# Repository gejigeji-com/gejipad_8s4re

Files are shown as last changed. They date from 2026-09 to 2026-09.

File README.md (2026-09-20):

# gejipad_8s4re

自作キーボード「gejipad_8s4re」のハードウェア設計データ(KiCad)を公開するリポジトリです。

> **Note:** このリポジトリにはハードウェア(回路図・基板データ)のみを収録しています。ファームウェアはQMK Firmwareへの統合を申請中(`gejigeji/gejipad_8s4re`)であり、本リポジトリには含まれません。

## 概要

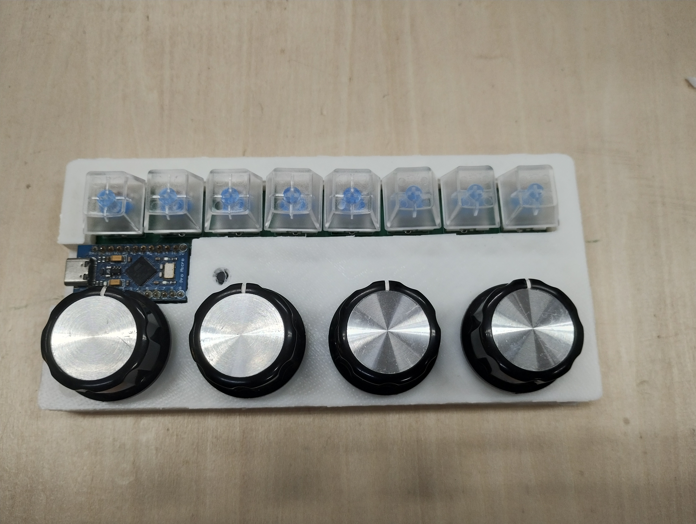
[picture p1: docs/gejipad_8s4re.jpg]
gejipad_8s4re


| 項目 | 内容 |
|---|---|
| キー数 | 8キー |
| ロータリーエンコーダ | 4基 |
| レイアウト | キー1列 + ロータリーエンコーダ1列 |
| MCU | ATmega32U4 |
| スイッチ | MX互換 |
| ファームウェア | [QMK Firmware](https://github.com/qmk/qmk_firmware) `gejigeji/gejipad_8s4re` として申請中(本リポジトリには含まれません) |

## リポジトリ構成

```
gejipad_8s4re/
├── gejipad_8s4re.kicad_pro   # KiCadプロジェクトファイル
├── gejipad_8s4re.kicad_sch   # 回路図
├── gejipad_8s4re.kicad_pcb   # 基板データ
├── libs/                     # 自作/追加ライブラリ(シンボル・フットプリント・3Dモデル)
├── production/                # 発注用データ(ガーバー・BOM・部品配置)・ケース
└── docs/                      # 回路図PDF・基板画像など
```

## 開発環境

- KiCad 7.0

## 基板の発注方法

`production/gerbers/` 内のガーバーデータをPCB製造業者(JLCPCBなど)にアップロード

## 組み立て

1. 部品は [`production/gejipad_8s4re-BOM.csv`](production/gejipad_8s4re-bom.csv) を参照
2. 組み立て方法は [`docs/assembly.md`](docs/assembly.md) を参照

## ファームウェアについて

本キーボードのファームウェアは [QMK Firmware](https://github.com/qmk/qmk_firmware) への統合を申請中です(統合先パス: `keyboards/gejigeji/gejipad_8s4re/`)。現時点では未マージのため、ハードウェア(本リポジトリ)とは別管理とし、キーマップ等のファームウェア関連ファイルはこのリポジトリには含めていません。

<!-- PRのURLが判明したら、ここに追記します -->

マージ後はQMK Firmwareの `keyboards/gejigeji/gejipad_8s4re/` に統合される予定です。

## ライセンス

本リポジトリのハードウェア設計データ(回路図・基板データ)は [CC BY-SA 4.0](https://creativecommons.org/licenses/by-sa/4.0/)(Creative Commons Attribution-ShareAlike 4.0 International)のもとで公開しています。改変・再配布・商用利用は自由ですが、クレジット表記(Attribution)と、改変版を同じライセンスで公開すること(ShareAlike)が条件となります。詳細は [LICENSE](./LICENSE) を参照してください。

ファームウェア部分は本リポジトリに含まれないため、このライセンスの対象外です。QMK Firmwareへの統合後は、QMK側のライセンス(GPLv2/v3)に従います。

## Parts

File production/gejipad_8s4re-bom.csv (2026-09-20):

No. | Reference | Category | Item | PartNumber | Manufacturer | Supplier | SupplierPN | Qty | Notes
1 | SW1 | スイッチ | タクトスイッチ6mm |  |  | 秋月電子通商 | 103647 | 1
2 | SW2, SW3, SW4, SW5 | スイッチ | ロータリーエンコーダー | EC12E2420801 | アルプスアルパイン株式会社 | 秋月電子通商 | 106357 | 4
3 | SW2, SW3, SW4, SW5 | つまみ（ノブ） | つまみ（ノブ） |  |  | 秋月電子通商 | 101000 | 4 | 6㎜軸に対応した任意のつまみが使用可能（直径35mmまで）
4 | SW6, SW7, SW8, SW9, SW10, SW11, SW12, SW13 | ソケット・コネクタ | Kailh Switch Socket | CPG151101S11 | Kailh | Amazon 遊舎工房 |  | 8
5 | SW6, SW7, SW8, SW9, SW10, SW11, SW12, SW13 | スイッチ | Cherry MX（キースイッチ） |  |  | Amazon 遊舎工房 |  | 8 | Cherry MX互換キースイッチが使用可能
6 | SW6, SW7, SW8, SW9, SW10, SW11, SW12, SW13 | キーキャップ | キーキャップ（1u）（Cherryプロファイル） |  |  | Amazon 遊舎工房 |  | 8
7 | U1 | ソケット・コネクタ | ロープロファイルピンヘッダー（12P） |  |  | 秋月電子通商 | 102900 | 2 | ピンヘッダー・ソケット、コンスルー等任意の方法で取り付け（ロータリーエンコーダーと干渉しないように取り付け高さ注意）
8 | U1 | ソケット・コネクタ | ロープロファイルピンソケット（12P） |  |  | 秋月電子通商 | 100661 | 2 | 同上
9 | U1 | マイコンボード | Pro Micro |  |  | Amazon 遊舎工房 |  | 1 | Pro Micro互換ボードが使用可能
10 | - | プリント基板 | プリント基板（gejipad_8s44re rev0.3a） |  | - | - | - | 1 | ガーバーファイルから製造
11 | - | ケース | ケース |  | - | - | - | 1 | STLファイルから出力
12 | - | ビス | M3x8mm タッピングビス |  |  | ミスミ モノタロウ ホームセンター |  | 11 | STLファイルから出力したケースを使用する場合

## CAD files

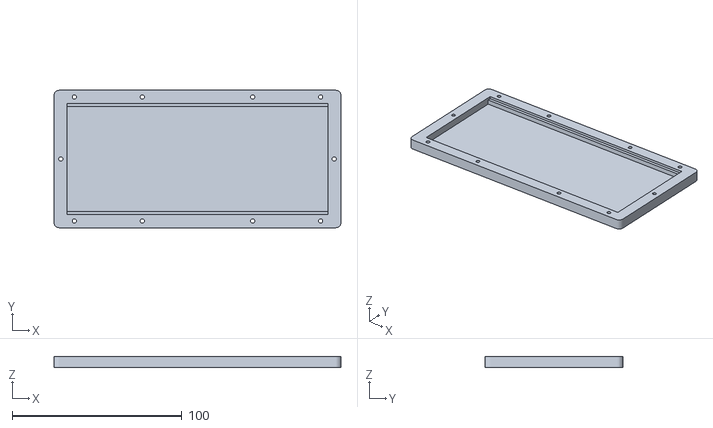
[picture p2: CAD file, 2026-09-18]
production/case_b.stl
169.0 x 81.0 x 6.60

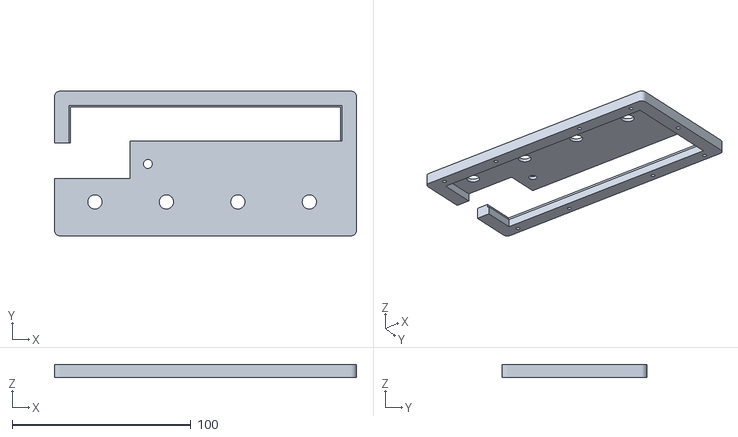
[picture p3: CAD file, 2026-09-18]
production/case_u.stl
169.0 x 81.0 x 7.00

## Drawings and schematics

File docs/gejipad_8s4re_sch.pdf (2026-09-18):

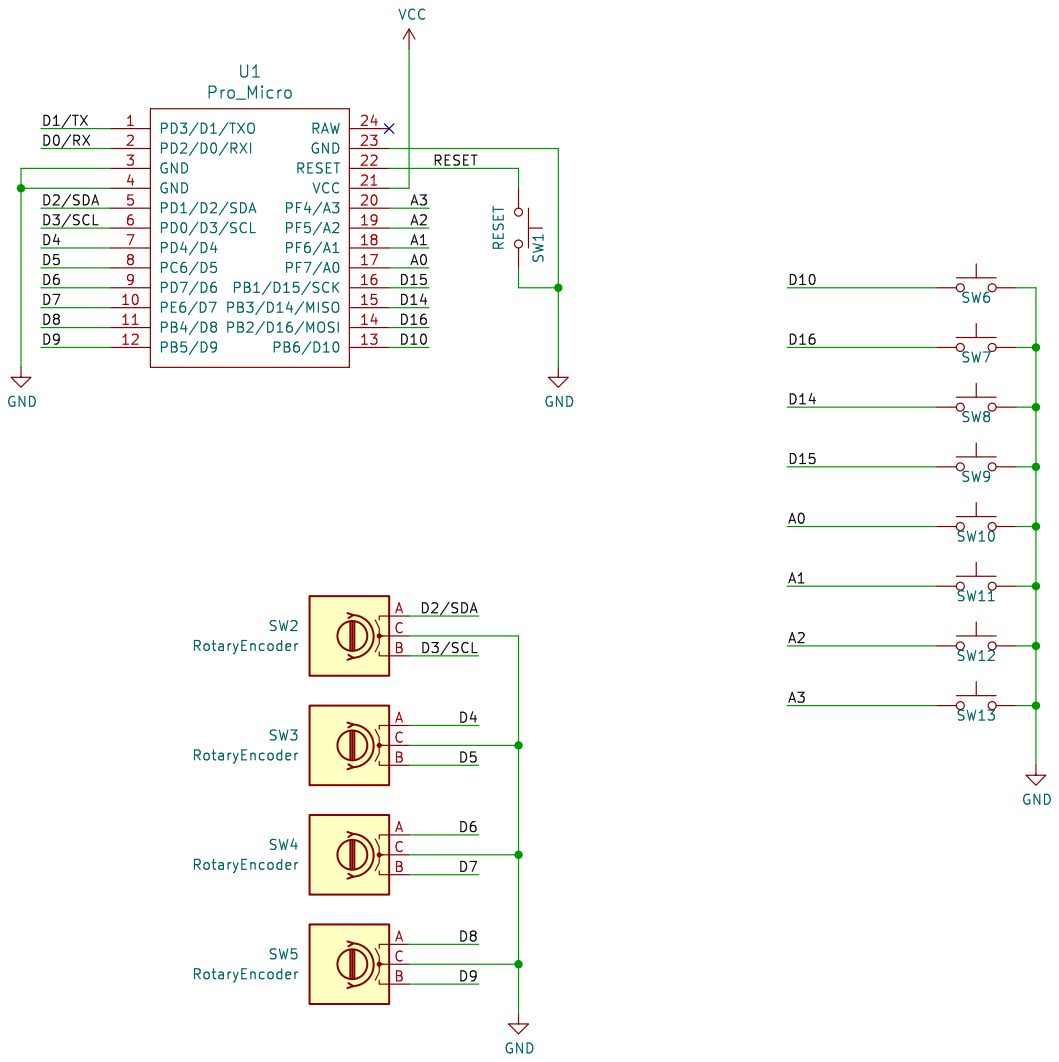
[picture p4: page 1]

File: gejipad_8s4re.kicad_sch Sheet: / gejigeji-com

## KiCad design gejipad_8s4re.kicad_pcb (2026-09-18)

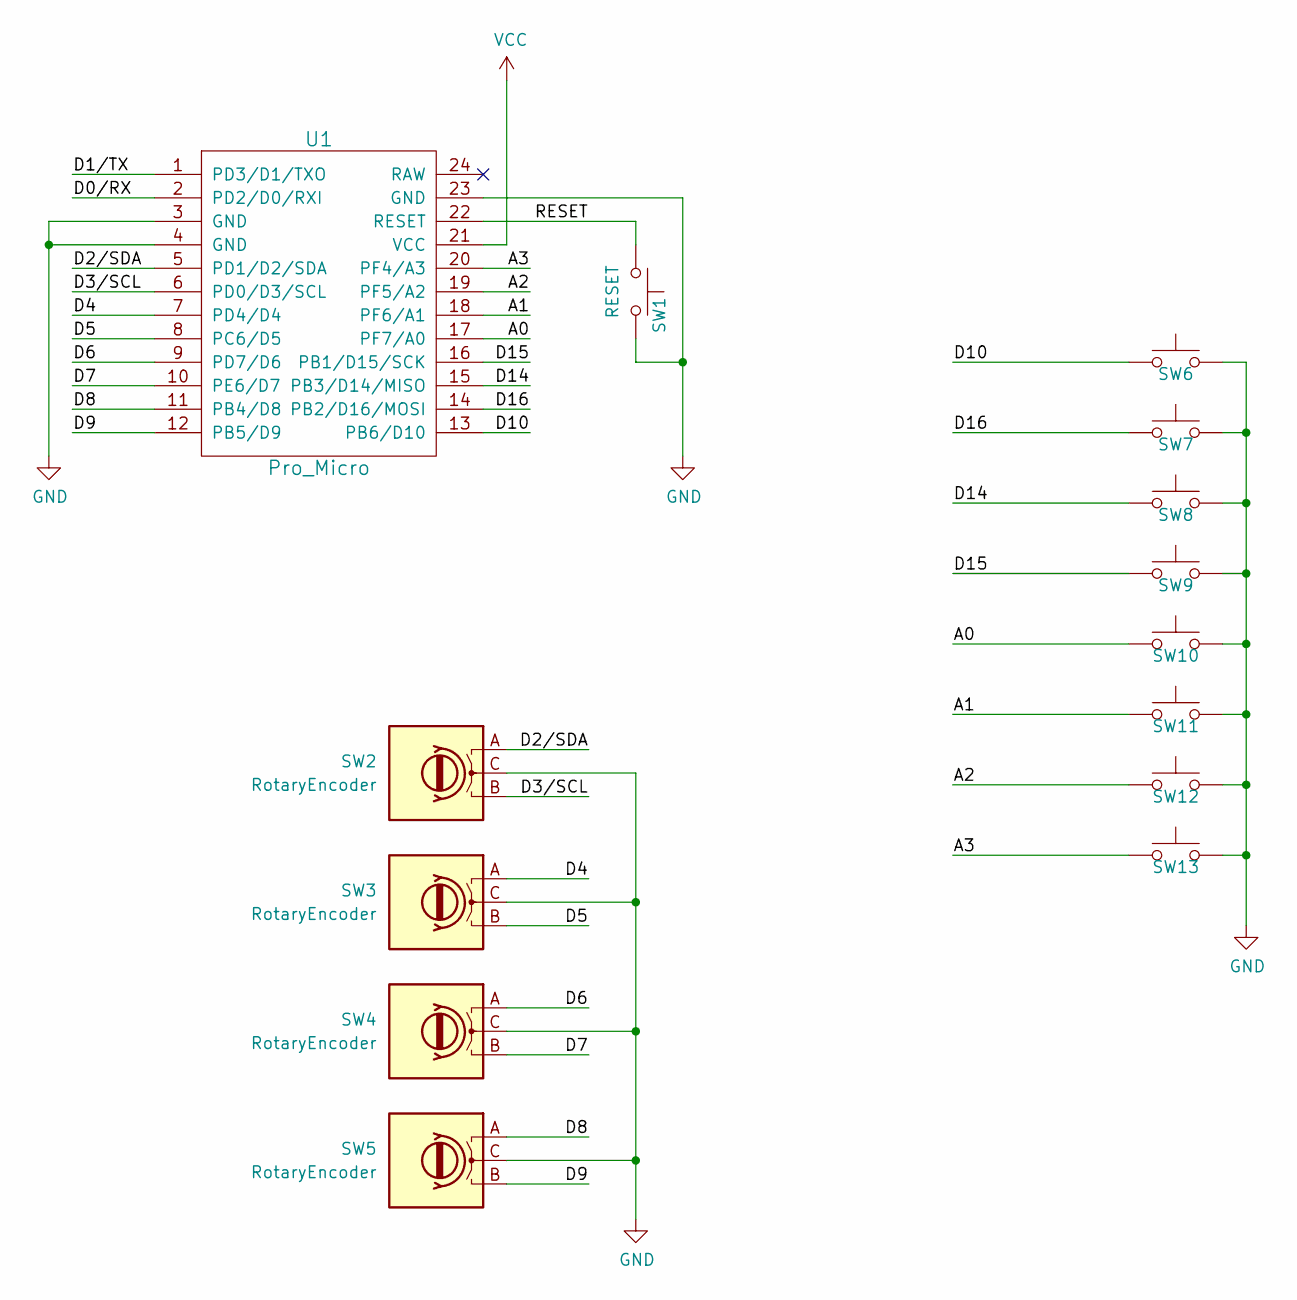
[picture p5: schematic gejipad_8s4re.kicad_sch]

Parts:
SW1: RESET; SW_PUSH_6mm
SW2, SW3, SW4, SW5: RotaryEncoder; RotaryEncoder_Alps_EC12E_Vertical_H20mm
SW6, SW7, SW8, SW9, SW10, SW11, SW12, SW13: SW_Push; SW_Cherry_MX1A_1.00u_PCB
U1: Pro_Micro; ProMicro

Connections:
/A0: SW10.1, U1.17 (PF7/A0)
/A1: SW11.1, U1.18 (PF6/A1)
/A2: SW12.1, U1.19 (PF5/A2)
/A3: SW13.1, U1.20 (PF4/A3)
/D0/RX: U1.2 (PD2/D0/RXI)
/D1/TX: U1.1 (PD3/D1/TXO)
/D2/SDA: SW2.A, U1.5 (PD1/D2/SDA)
/D3/SCL: SW2.B, U1.6 (PD0/D3/SCL)
/D4: SW3.A, U1.7 (PD4/D4)
/D5: SW3.B, U1.8 (PC6/D5)
/D6: SW4.A, U1.9 (PD7/D6)
/D7: SW4.B, U1.10 (PE6/D7)
/D8: SW5.A, U1.11 (PB4/D8)
/D9: SW5.B, U1.12 (PB5/D9)
/D10: SW6.1, U1.13 (PB6/D10)
/D14: SW8.1, U1.15 (PB3/D14/MISO)
/D15: SW9.1, U1.16 (PB1/D15/SCK)
/D16: SW7.1, U1.14 (PB2/D16/MOSI)
/RESET: SW1.1, U1.22 (RESET)
GND: SW1.2, SW2.C, SW3.C, SW4.C, SW5.C, SW6.2, SW7.2, SW8.2, SW9.2, SW10.2, SW11.2, SW12.2, SW13.2, U1.3 (GND), U1.4 (GND), U1.23 (GND)
VCC: U1.21 (VCC)

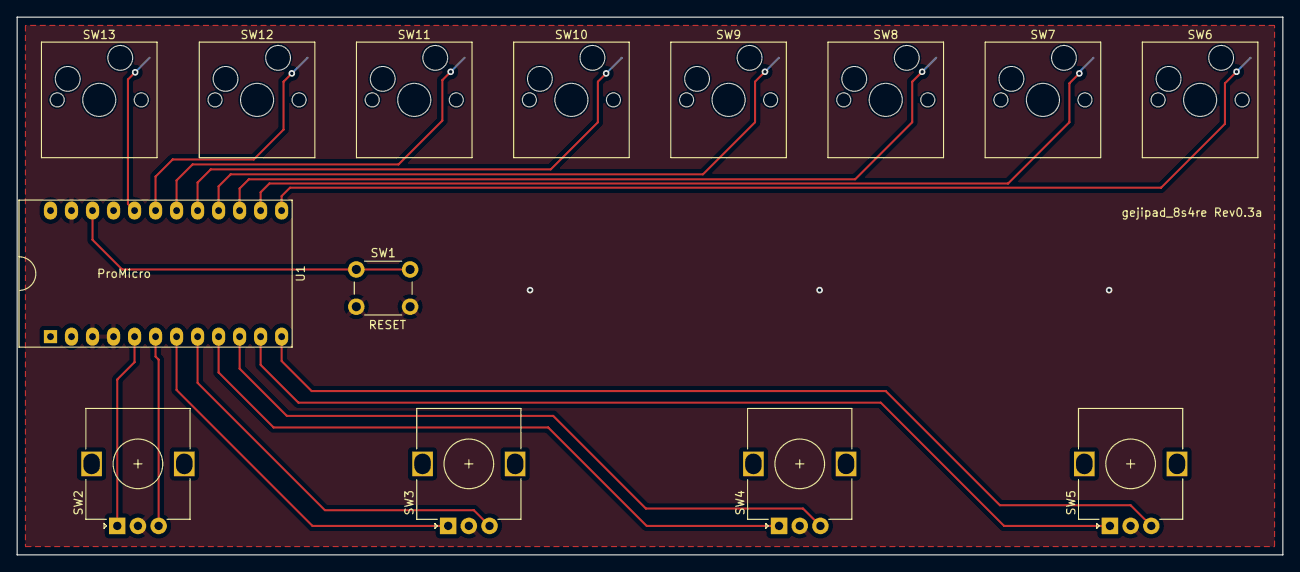
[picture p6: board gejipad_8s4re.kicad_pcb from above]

Board: 2 copper layers, 153.0 x 65.0 mm, 14 parts (0 on the bottom side), 18 nets.

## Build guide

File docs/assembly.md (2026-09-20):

# 組み立てマニュアル

このドキュメントは、本キーボードの組み立て手順をまとめたものです。使用部品は [部品表 (BOM)](../production/gejipad_8s4re-bom.csv) を参照してください。

## 事前準備

- ガーバーファイルを使用してプリント基板を発注する
- STLファイルを3Dプリンターで出力する（ケースを使用する場合。必要に応じて）

## 組み立て手順

### 1. Kailh Switch Socketのはんだ付け（SW6-13）

プリント基板にKailh製のスイッチソケットをはんだ付けします。キースイッチ中央の穴をふさがないよう、取り付け向きに注意してください。

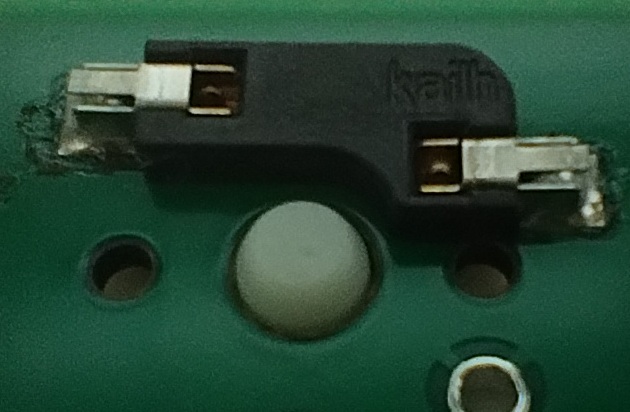
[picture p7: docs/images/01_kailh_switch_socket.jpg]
Kailh Switch Socketのはんだ付け


### 2. タクトスイッチのはんだ付け（SW1）

リセット用のタクトスイッチをはんだ付けします。

### 3. ロープロファイルソケット・ピンヘッダーのはんだ付け（U1）

Pro Micro用のソケットとピンヘッダーをはんだ付けします。

傾いた状態ではんだ付けするとPro Microが正しく挿さらなくなるため、プリント基板・ソケット・ピンヘッダー・Pro Microを実際に重ねて位置を合わせた状態ではんだ付けするのがおすすめです。

- プリント基板側にはソケットを、Pro Micro側にはピンヘッダーをはんだ付けする
- ピンヘッダーで直接はんだ付けする方法、コンスルーを使用する方法など、必要に応じて対応可能
- ロータリーエンコーダーのつまみと干渉しないよう、高さに注意すること

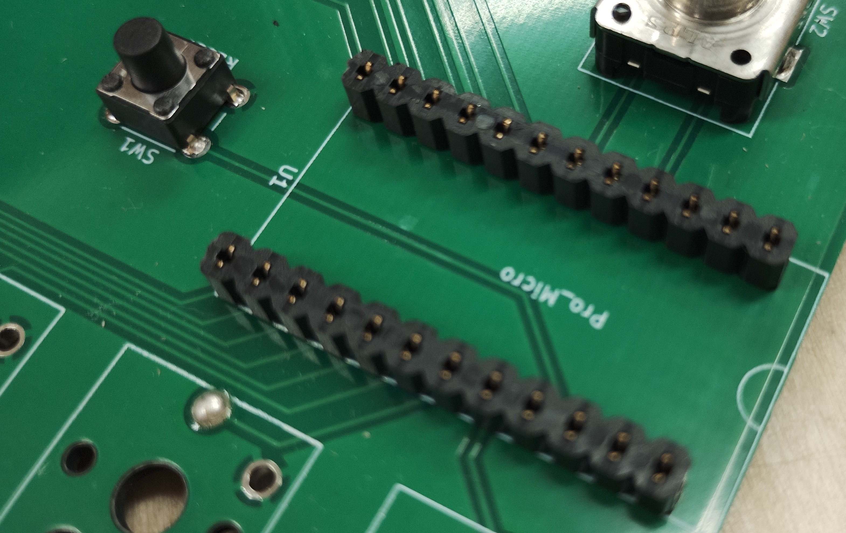
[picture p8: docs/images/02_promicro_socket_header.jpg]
ソケット・ピンヘッダーの取り付け


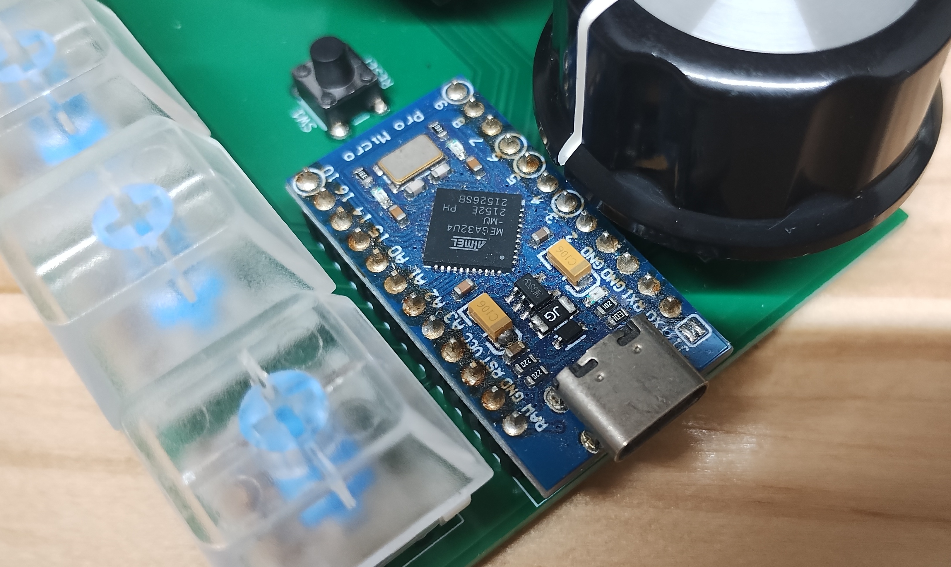
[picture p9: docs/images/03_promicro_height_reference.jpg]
Pro Microとロータリーエンコーダーのつまみの高さの目安


### 4. ロータリーエンコーダーのはんだ付け（SW2-5）

### 5. ケースへの組み込み（必要に応じて）

M3のタッピングビスで、蓋と底を固定します。

### 6. ロータリーエンコーダーへのつまみの取り付け

### 7. キースイッチ・キーキャップの取り付け
